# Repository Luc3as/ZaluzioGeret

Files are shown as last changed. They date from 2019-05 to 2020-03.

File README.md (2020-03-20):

# Zaluzio Geret
Automated smart blinds retrofit device with WiFi , MQTT and light measurement capability.



## Bill of material
* [Wemos D1 mini](http://s.click.aliexpress.com/e/b7xoMFF6) 
* [180 degree servo](http://s.click.aliexpress.com/e/cCIS5ETW)
* [LDR 5516 photoresistor](http://s.click.aliexpress.com/e/sKHeBEs)
* [NPN Transistor](http://s.click.aliexpress.com/e/bSLbOB7K)
* [Tactile push buttons](http://s.click.aliexpress.com/e/0rbMNuk)
* [10k Resistors](http://s.click.aliexpress.com/e/boawi0Ak)
* Some spring, hard to specify dimensions and power
* Some basic soldering equipment and skills

## Settings
You can redefine some default settings through Settings.h file. It is pretty self-explanatory I think.

## Usage
There is WiFi Manager on board so after burning the firmware, device is in AP mode, default password for connecting to AP is: configure.
Default account for configuring / controlling the device is admin with password: password

After connecting to WiFi, there is UI configuration interface, you can find device IP address through serial terminal or through in your router, or through scanning the network. Device hostname is ZaluzioGeret-MAC_END.

There are settings for specifiing MIN and MAX angle of rotation, and reverse direction of inner logic.

There are 2 buttons connected, UP and DOWN, each short press control the servo with 5° in respective direction. Short pressing of both buttons resets the servo in middle position. 
Long press of each button moves the servo to the MIN or MAX position defined. Long pressing of both buttons starts the LightFinder procedure. 
LightFinder procedure moves the servo to MIN position, and then continually measure light after each move. Then it move to the position in which highest light was measured. 

Long pressing of both buttons for 8 seconds resets the WiFi settings, putting the device into AP configuration mode. 

## Slave device controll
There is option in settings to setup Slave device ID which is automatically generated hostname which you can see in top of home screen. I assume using identical settings of PUB and SUB topic prefixes and also angles. 

When slave device ID is set, after pressing button, MQTT command will be sent to slave device and thus linking these together.

If you want to controll multiple devices remotely, not through buttons, you can easily done it in Home automation system, for example automation would have 2 actions, send command to 2 different topics. 

## MQTT Commands
```
  MQTTPUBTOPIC/hostname/LWT - Where status of device is sent 
  MQTTSUBTOPIC/hostname/Rotate  - Command for controlling angle of servo number expected
  MQTTSUBTOPIC/hostname/FindLight - Command for start LightFinder procedure. On expected
  MQTTPUBTOPIC/hostname/Light - Here is light measured sent
  MQTTPUBTOPIC/hostname/Angle - Here is current angle of servo sent
```

## API call / rest command
This call will start LightFinder procedure. 
You have to be authenticated or send basic auth with request.
``` 
ip.of.dev.ice/lightcontrol
```
This call will move servo to desired angle. 
You have to be authenticated or send basic auth with request.
``` 
ip.of.dev.ice/servocontrol?angle=XX
```

## Example Home Assisant configuration
```yaml
cover:
  - platform: mqtt
    name: "Žalúzie spálňa lavé"
    device_class: "blind"
    availability_topic: "stat/ZaluzioGeret-3252d1/LWT"
    qos: 0
    retain: false
    payload_available: "Online"
    payload_not_available: "Offline"
    optimistic: false
    value_template: '{{ value.x }}'
    tilt_command_topic: 'cmnd/ZaluzioGeret-3252d1/Rotate'
    tilt_status_topic: 'stat/ZaluzioGeret-3252d1/Angle'
    tilt_min: 0
    tilt_max: 180
    tilt_closed_value: 180
    tilt_opened_value: 90
    
  - platform: mqtt
    name: "Žalúzie spálňa pravé"
    device_class: "blind"
    availability_topic: "stat/ZaluzioGeret-5d26b9/LWT"
    qos: 0
    retain: false
    payload_available: "Online"
    payload_not_available: "Offline"
    optimistic: false
    value_template: '{{ value.x }}'
    tilt_command_topic: 'cmnd/ZaluzioGeret-5d26b9/Rotate'
    tilt_status_topic: 'stat/ZaluzioGeret-5d26b9/Angle'
    tilt_min: 0
    tilt_max: 180
    tilt_closed_value: 180
    tilt_opened_value: 90

  - platform: group
    name: "Žalúzie spálňa"
    entities:
      - cover.zaluzie_spalna_lave
      - cover.zaluzie_spalna_prave
```

## Wiring scheme
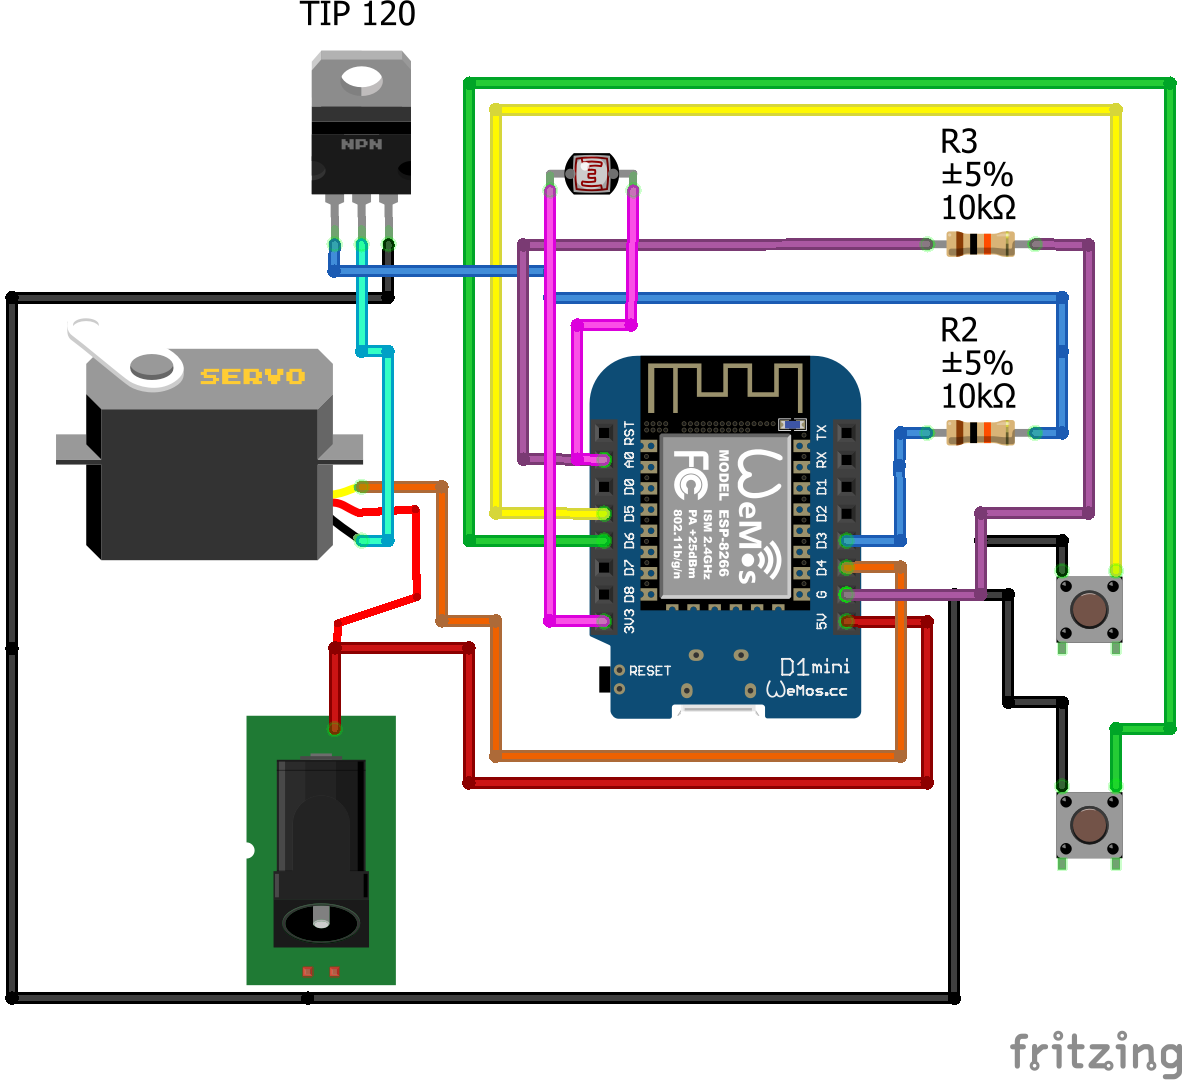
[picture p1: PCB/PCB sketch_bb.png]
Wiring scheme


## Physical installation
Device is mounted to window frame by self adhesive tape by 3M.

For cable routing I used sticky cable trunking with name MONTERA. 

All parts for 3D printing are on [thingiverse project page](https://www.thingiverse.com/thing:3679293)







### If You liked my work, You can buy me a coffee :)

<a class="" target="_blank" href="https://www.buymeacoffee.com/luc3as">Buy Me A Coffee</a>

### Or send some crypto

<a class="" target="_blank" href="https://lukasporubcan.sk/donate">Donate Bitcoin</a>

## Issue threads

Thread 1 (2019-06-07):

Some questions

davidhrbaty, 2019-06-07:
Hello Lukas,

Thank you for sharing this project. It looks very similar to what I want to build in the upcoming weeks.  I have a couple of questions.
When do you plan to share 3D models for the case?
How did you solve the problem with opening the window due to the power cable?
Did you consider mounting servo inside the sunblinds mechanism directly?

Thank you. Have a nice day.

Luc3as, 2019-06-08:
Hi,
good to read this, as always I was doing another projects and didn't get back to all TODOs I planned.
However today I slightly modified the base plate for this device and so right after that I uploaded it to thingiverse. You can find it here https://www.thingiverse.com/thing:3679293
I ran cables in thin cable organizer so there is no problem with opening the windows, I attached the cables in corner where the hinges are , and there is little reserve in bottom of window board.
Yes actually this is second or third design and I was playing with more options, at first I tried to pull ball chain with stepper motor, but it was too weak in my case, even after modifying the driver board. Second attemp was with continuos rotation servo, it is very similiar to this design, and it was doing great job, but I dropped this option because I would need to sense position of blinds somehow, I am sure there are ways to do this, I was thinking about some magnet attached to ball chain, and then sensing this magnet passing by reed switch somewhere on side of device. Or there could be some end stop switches attached but this means more cabling aand it would cause lower WAF (wife acceptance factor) :D
anyway this version is compatible with continuos rotation servos.
Sure I was thinking about putting all magic into the blinds cover, but  in my case I have very slim profiled sunblinds, so there is not enough room for this big servo. I saw some projects where bigger (older I guess) sunblinds was used and all electronics and motor was attached right there. You can find inspiration here if that is your case https://www.youtube.com/watch?v=s8kW8CoRJy0

davidhrbaty, 2019-06-10:
Hello,
Thank you for sharing your STL files. I will try it this weekend. Yes I know, that WAF is a top priority in all households :D. I was thinking about using the SG90 servo motor, which is very tiny and it can be integrated into sunblinds, but there can be a problem with torque. Now I'm looking, that you are from Slovakia too, so we can talk in our mother language ;).

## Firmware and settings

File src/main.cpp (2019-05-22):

/** The MIT License (MIT)

Copyright (c) 2019 Lukas Luc3as Porubcan

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
THE SOFTWARE IS PROVIDED "AS IS", WITHOUT WARRANTY OF ANY KIND, EXPRESS OR
IMPLIED, INCLUDING BUT NOT LIMITED TO THE WARRANTIES OF MERCHANTABILITY,
FITNESS FOR A PARTICULAR PURPOSE AND NONINFRINGEMENT. IN NO EVENT SHALL THE
AUTHORS OR COPYRIGHT HOLDERS BE LIABLE FOR ANY CLAIM, DAMAGES OR OTHER
LIABILITY, WHETHER IN AN ACTION OF CONTRACT, TORT OR OTHERWISE, ARISING FROM,
OUT OF OR IN CONNECTION WITH THE SOFTWARE OR THE USE OR OTHER DEALINGS IN THE
SOFTWARE.
*/

 /**********************************************
 * Edit Settings.h for personalization
 ***********************************************/

#include "Settings.h"

#define VERSION "1.3"

#define CONFIG "/conf.txt"

/* Useful Constants */
#define SECS_PER_MIN  (60UL)
#define SECS_PER_HOUR (3600UL)

/* Useful Macros for getting elapsed time */
#define numberOfSeconds(_time_) (_time_ % SECS_PER_MIN)  
#define numberOfMinutes(_time_) ((_time_ / SECS_PER_MIN) % SECS_PER_MIN) 
#define numberOfHours(_time_) (_time_ / SECS_PER_HOUR)

String hostname = "ZaluzioGeret-" + String(ESP.getChipId(), HEX);

WiFiUDP ntpUDP;
// Time 
NTPClient timeClient(ntpUDP, ntp_server , UtcOffset * 3600, 120000);

long lastEpoch = 0;
long firstEpoch = 0;
long displayOffEpoch = 0;
String lastMinute = "xx";
String lastSecond = "xx";
String lastReportStatus = "";

//declairing prototypes
void configModeCallback (WiFiManager *myWiFiManager);
int8_t getWifiQuality();

ESP8266WebServer server(WEBSERVER_PORT);
ESP8266HTTPUpdateServer serverUpdater;

String WEB_ACTIONS =  "<a class='w3-bar-item w3-button' href='/'><i class='fa fa-home'></i> Home</a>"
                      "<a class='w3-bar-item w3-button' href='/configure'><i class='fa fa-cog'></i> Configure</a>"
                      "<a class='w3-bar-item w3-button' href='/systemreset' onclick='return confirm(\"Do you want to reset to default settings?\")'><i class='fa fa-undo'></i> Reset Settings</a>"
                      "<a class='w3-bar-item w3-button' href='/forgetwifi' onclick='return confirm(\"Do you want to forget to WiFi connection?\")'><i class='fa fa-wifi'></i> Forget WiFi</a>"
                      "<a class='w3-bar-item w3-button' href='/update'><i class='fa fa-wrench'></i> Firmware Update</a>"
                      "<a class='w3-bar-item w3-button' href='/restart' onclick='return confirm(\"Do you want to restart device? Settings will persist.\")'><i class='fa fa-power-off'></i> Restart device</a>"
                      "<a class='w3-bar-item w3-button' href='https://github.com/Luc3as' target='_blank'><i class='fa fa-question-circle'></i> About</a>";
                          
String CHANGE_FORM =  "<form class='w3-container' action='/updateconfig' method='get'><h2>Device Config:</h2>"
                      "<p><label>MQTT Server address</label><input class='w3-input w3-border w3-margin-bottom' type='text' name='mqttAddress' value='%MQTTADDRESS%' maxlength='60'></p>"
                      "<p><label>MQTT Server Port</label><input class='w3-input w3-border w3-margin-bottom' type='text' name='mqttPort' value='%MQTTPORT%' maxlength='5'  onkeypress='return isNumberKey(event)'></p>"
                      "<p><label>MQTT Server User</label><input class='w3-input w3-border w3-margin-bottom' type='text' name='mqttUser' value='%MQTTUSER%' maxlength='30'></p>"
                      "<p><label>MQTT Server Password </label><input class='w3-input w3-border w3-margin-bottom' type='password' name='mqttPass' value='%MQTTPASS%'></p><hr>"
                      "<p><label>MQTT subscribe topic prefix ( prefix/hostname/topic )</label><input class='w3-input w3-border w3-margin-bottom' type='text' name='mqttSubTopic' value='%MQTTSUBTOPIC%' maxlength='30'></p>"
                      "<p><label>MQTT publish topic prefix ( prefix/hostname/topic )</label><input class='w3-input w3-border w3-margin-bottom' type='text' name='mqttPubTopic' value='%MQTTPUBTOPIC%' maxlength='30'></p>"
                      "<p><label>MQTT slave ID </label><input class='w3-input w3-border w3-margin-bottom' type='text' name='mqttSlaveId' value='%MQTTSLAVEID%' maxlength='30'></p><hr>"
                      "<p><input name='isreversedcontrol' class='w3-check w3-margin-top' type='checkbox' %IS_REVERSED_CONTROL%> Reverse direction of servo</p><hr>"
                      "<p><label>Minimal servo angle</label><input class='w3-input w3-border w3-margin-bottom' type='number' name='minAngle' value='%MINANGLE%' min'0' max'180'></p>"
                      "<p><label>Maximal servo angle</label><input class='w3-input w3-border w3-margin-bottom' type='number' name='maxAngle' value='%MAXANGLE%' min'0' max'180'></p>"
                      "<p><label>Maximal light intensity ( 0 - 1023 )</label><input class='w3-input w3-border w3-margin-bottom' type='number' name='maxLight' value='%MAXLIGHT%' min'0' max'1023'></p>";
                      
String THEME_FORM =   "<p>Theme Color <select class='w3-option w3-padding' name='theme'>%THEME_OPTIONS%</select></p>"
                      "<p>Clock Sync (minutes) <select class='w3-option w3-padding' name='refresh'>%OPTIONS%</select></p>"
                      "<p><label>UTC Time Offset</label><input class='w3-input w3-border w3-margin-bottom' type='text' name='utcoffset' value='%UTCOFFSET%' maxlength='12'></p><hr>"
                      "<p><input name='isBasicAuth' class='w3-check w3-margin-top' type='checkbox' %IS_BASICAUTH_CHECKED%> Use Security Credentials for Configuration Changes</p>"
                      "<p><label>User ID (for this interface)</label><input class='w3-input w3-border w3-margin-bottom' type='text' name='userid' value='%USERID%' maxlength='20'></p>"
                      "<p><label>Password </label><input class='w3-input w3-border w3-margin-bottom' type='password' name='stationpassword' value='%STATIONPASSWORD%'></p>"
                      "<button class='w3-button w3-block w3-grey w3-section w3-padding' type='submit'>Save</button></form>";

String COLOR_THEMES = "<option>red</option>"
                      "<option>pink</option>"
                      "<option>purple</option>"
                      "<option>deep-purple</option>"
                      "<option>indigo</option>"
                      "<option>blue</option>"
                      "<option>light-blue</option>"
                      "<option>cyan</option>"
                      "<option>teal</option>"
                      "<option>green</option>"
                      "<option>light-green</option>"
                      "<option>lime</option>"
                      "<option>khaki</option>"
                      "<option>yellow</option>"
                      "<option>amber</option>"
                      "<option>orange</option>"
                      "<option>deep-orange</option>"
                      "<option>blue-grey</option>"
                      "<option>brown</option>"
                      "<option>grey</option>"
                      "<option>dark-grey</option>"
                      "<option>black</option>"
                      "<option>w3schools</option>";

void writeSettings();
void handleWifiReset();
void handleServoControl();
void handleLightControl();
void handleUpdateConfig();
void handleConfigure();
void handleRestart();
void displayDeviceStatus();
void lightFinder();


void flashLED(int number, int delayTime) {
  for (int inx = 0; inx < number; inx++) {
      delay(delayTime);
      digitalWrite(externalLight, LOW);
      delay(delayTime);
      digitalWrite(externalLight, HIGH);
      delay(delayTime);
  }
}

void readSettings() {
  if (SPIFFS.exists(CONFIG) == false) {
    Serial.println("Settings File does not yet exists.");
    writeSettings();
    return;
  }
  File fr = SPIFFS.open(CONFIG, "r");
  String line;
  while(fr.available()) {
    line = fr.readStringUntil('\n');

    if (line.indexOf("UtcOffset=") >= 0) {
      UtcOffset = line.substring(line.lastIndexOf("UtcOffset=") + 10).toFloat();
      Serial.println("UtcOffset=" + String(UtcOffset));
    }
    if (line.indexOf("refreshRate=") >= 0) {
      minutesBetweenDataRefresh = line.substring(line.lastIndexOf("refreshRate=") + 12).toInt();
      Serial.println("minutesBetweenDataRefresh=" + String(minutesBetweenDataRefresh));
    }
    if (line.indexOf("themeColor=") >= 0) {
      themeColor = line.substring(line.lastIndexOf("themeColor=") + 11);
      themeColor.trim();
      Serial.println("themeColor=" + themeColor);
    }
    if (line.indexOf("IS_BASIC_AUTH=") >= 0) {
      IS_BASIC_AUTH = line.substring(line.lastIndexOf("IS_BASIC_AUTH=") + 14).toInt();
      Serial.println("IS_BASIC_AUTH=" + String(IS_BASIC_AUTH));
    }
    if (line.indexOf("www_username=") >= 0) {
      String temp = line.substring(line.lastIndexOf("www_username=") + 13);
      temp.trim();
      temp.toCharArray(www_username, sizeof(temp));
      Serial.println("www_username=" + String(www_username));
    }
    if (line.indexOf("www_password=") >= 0) {
      String temp = line.substring(line.lastIndexOf("www_password=") + 13);
      temp.trim();
      temp.toCharArray(www_password, sizeof(temp));
      Serial.println("www_password=" + String(www_password));
    }
    if (line.indexOf("DISPLAYCLOCK=") >= 0) {
      DISPLAYCLOCK = line.substring(line.lastIndexOf("DISPLAYCLOCK=") + 13).toInt();
      Serial.println("DISPLAYCLOCK=" + String(DISPLAYCLOCK));
    }
    if (line.indexOf("IS_REVERSED_CONTROL=") >= 0) {
      IS_REVERSED_CONTROL = line.substring(line.lastIndexOf("IS_REVERSED_CONTROL=") + 20).toInt();
      Serial.println("IS_REVERSED_CONTROL=" + String(IS_REVERSED_CONTROL));
    }    
    if (line.indexOf("MQTTADDRESS=") >= 0) {
      MQTTADDRESS = line.substring(line.lastIndexOf("MQTTADDRESS=") + 12);
      MQTTADDRESS.trim();
      Serial.println("MQTTADDRESS=" + String(MQTTADDRESS));
    }
    if (line.indexOf("MQTTPORT=") >= 0) {
      MQTTPORT = line.substring(line.lastIndexOf("MQTTPORT=") + 9).toInt();
      Serial.println("MQTTPORT=" + String(MQTTPORT));
    }    
    if (line.indexOf("MQTTUSER=") >= 0) {
      MQTTUSER = line.substring(line.lastIndexOf("MQTTUSER=") + 9);
      MQTTUSER.trim();
      Serial.println("MQTTUSER=" + String(MQTTUSER));
    }
    if (line.indexOf("MQTTPASS=") >= 0) {
      MQTTPASS = line.substring(line.lastIndexOf("MQTTPASS=") + 9);
      MQTTPASS.trim();
      Serial.println("MQTTPASS=" + String(MQTTPASS));
    }   
    if (line.indexOf("MQTTSUBTOPIC=") >= 0) {
      MQTTSUBTOPIC = line.substring(line.lastIndexOf("MQTTSUBTOPIC=") + 13);
      MQTTSUBTOPIC.trim();
      Serial.println("MQTTSUBTOPIC=" + String(MQTTSUBTOPIC));
    } 
    if (line.indexOf("MQTTPUBTOPIC=") >= 0) {
      MQTTPUBTOPIC = line.substring(line.lastIndexOf("MQTTPUBTOPIC=") + 13);
      MQTTPUBTOPIC.trim();
      Serial.println("MQTTPUBTOPIC=" + String(MQTTPUBTOPIC));
    }
    if (line.indexOf("MQTTSLAVEID=") >= 0) {
      MQTTSLAVEID = line.substring(line.lastIndexOf("MQTTSLAVEID=") + 12);
      MQTTSLAVEID.trim();
      Serial.println("MQTTSLAVEID=" + String(MQTTSLAVEID));
    }
    if (line.indexOf("MINANGLE=") >= 0) {
      MINANGLE = line.substring(line.lastIndexOf("MINANGLE=") + 9).toInt();
      Serial.println("MINANGLE=" + String(MINANGLE));
    }
    if (line.indexOf("MAXANGLE=") >= 0) {
      MAXANGLE = line.substring(line.lastIndexOf("MAXANGLE=") + 9).toInt();
      Serial.println("MAXANGLE=" + String(MAXANGLE));
    }      
    if (line.indexOf("MAXLIGHT=") >= 0) {
      MAXLIGHT = line.substring(line.lastIndexOf("MAXLIGHT=") + 9).toInt();
      Serial.println("MAXLIGHT=" + String(MAXLIGHT));
    }         
  }
  fr.close();
  timeClient.setTimeOffset(UtcOffset * 3600);
  LWTTopic = MQTTPUBTOPIC + "/" + hostname + "/LWT";
  SUBTopic = MQTTSUBTOPIC + "/" + hostname + "/Rotate";
  SUBTopicLight = MQTTSUBTOPIC + "/" + hostname + "/FindLight";
  PUBTopicLight = MQTTPUBTOPIC + "/" + hostname + "/Light";
  PUBTopicAngle = MQTTPUBTOPIC + "/" + hostname + "/Angle";
  SlaveTopic = MQTTSUBTOPIC + "/" + MQTTSLAVEID + "/Rotate";

}

void writeSettings() {
  // Save decoded message to SPIFFS file for playback on power up.
  File f = SPIFFS.open(CONFIG, "w");
  if (!f) {
    Serial.println("File open failed!");
  } else {
    Serial.println("Saving settings now...");
    f.println("UtcOffset=" + String(UtcOffset));
    f.println("refreshRate=" + String(minutesBetweenDataRefresh));
    f.println("themeColor=" + themeColor);
    f.println("IS_BASIC_AUTH=" + String(IS_BASIC_AUTH));
    f.println("www_username=" + String(www_username));
    f.println("www_password=" + String(www_password));
    f.println("DISPLAYCLOCK=" + String(DISPLAYCLOCK));
    f.println("IS_REVERSED_CONTROL=" + String(IS_REVERSED_CONTROL));
    f.println("MQTTADDRESS=" + String(MQTTADDRESS));
    f.println("MQTTPORT=" + String(MQTTPORT));
    f.println("MQTTUSER=" + String(MQTTUSER));
    f.println("MQTTPASS=" + String(MQTTPASS));
    f.println("MQTTSUBTOPIC=" + String(MQTTSUBTOPIC));
    f.println("MQTTPUBTOPIC=" + String(MQTTPUBTOPIC));
    f.println("MQTTSLAVEID=" + String(MQTTSLAVEID));
    f.println("MINANGLE=" + String(MINANGLE));
    f.println("MAXANGLE=" + String(MAXANGLE));
    f.println("MAXLIGHT=" + String(MAXLIGHT));
  }
  f.close();
  readSettings();
  timeClient.setTimeOffset(UtcOffset * 3600);
}

void findMDNS() {
  if ( ENABLE_OTA == false) {
    return; // nothing to do here
  }
  // We now query our network for 'web servers' service
  // over tcp, and get the number of available devices
  int n = MDNS.queryService("mqtt", "tcp");
  if (n == 0) {
    Serial.println("no services found - make sure server is turned on");
    return;
  }
  Serial.println("*** Looking for MQTT over mDNS");
  for (int i = 0; i < n; ++i) {
    // Going through every available service,
    // we're searching for the one whose hostname
    // matches what we want, and then get its IP
    Serial.println("Found: " + MDNS.hostname(i));
    if (MDNS.hostname(i) == "mqtt.local") {
      IPAddress serverIp = MDNS.IP(i);
      String MQTTServer = serverIp.toString();
      int16_t MQTTPort = MDNS.port(i); // save the port
      Serial.println("*** Found OctoPrint Server " + MDNS.hostname(i) + " http://" + MQTTServer + ":" + MQTTPort);
      writeSettings(); // update the settings
    }
  }
}

boolean authentication() {
  if (IS_BASIC_AUTH && (strlen(www_username) >= 1 && strlen(www_password) >= 1)) {
    return server.authenticate(www_username, www_password);
  } 
  return true; // Authentication not required
}

String getHeader(boolean refresh=false) {
  String menu = WEB_ACTIONS;

  String html = "<!DOCTYPE HTML>";
  html += "<html><head><title>ZaluzioGeret</title><link rel='icon' href='data:;base64,='>";
  html += "<meta charset='UTF-8'>";
  html += "<meta name='viewport' content='width=device-width, initial-scale=1'>";
  if (refresh) {
    html += "<meta http-equiv=\"refresh\" content=\"15\">";
  }
  html += "<link rel='stylesheet' href='https://www.w3schools.com/w3css/4/w3.css'>";
  html += "<link rel='stylesheet' href='https://www.w3schools.com/lib/w3-theme-" + themeColor + ".css'>";
  html += "<link rel='stylesheet' href='https://use.fontawesome.com/releases/v5.8.1/css/all.css' integrity='sha384-50oBUHEmvpQ+1lW4y57PTFmhCaXp0ML5d60M1M7uH2+nqUivzIebhndOJK28anvf' crossorigin='anonymous'>";
  html += "</head><body>";
  html += "<nav class='w3-sidebar w3-bar-block w3-card' style='margin-top:88px' id='mySidebar'>";
  html += "<div class='w3-container w3-theme-d2'>";
  html += "<span onclick='closeSidebar()' class='w3-button w3-display-topright w3-large'><i class='fa fa-times'></i></span>";
  html += "<div class='w3-cell w3-left w3-xxxlarge' style='width:60px'><i class='fa fa-cloud-sun'></i></div>";
  html += "<div class='w3-padding'>Menu</div></div>";
  html += menu;
  html += "</nav>";
  html += "<header class='w3-top w3-bar w3-theme'><button class='w3-bar-item w3-button w3-xxxlarge w3-hover-theme' onclick='openSidebar()'><i class='fa fa-bars'></i></button><h2 class='w3-bar-item'>Zaluzio Geret</h2></header>";
  html += "<script>";
  html += "function openSidebar(){document.getElementById('mySidebar').style.display='block'}function closeSidebar(){document.getElementById('mySidebar').style.display='none'}closeSidebar();";
  html += "</script>";
  html += "<br><div class='w3-container w3-large' style='margin-top:88px'>";
  return html;
}
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
void loop() {

  now = millis();
   
  //Get Time Update
  if((getMinutesFromLastRefresh() >= minutesBetweenDataRefresh) || lastEpoch == 0) {
    getUpdateTime();
  }

  if (WEBSERVER_ENABLED) {
    server.handleClient();
  }
  if (ENABLE_OTA) {
    ArduinoOTA.handle();
  }

  // Check MQTT connection
  if (!client.connected()) {
      reconnectMQTT();
  }

  // MQTT client loop check new messages
  client.loop();

  // Measure the light intensity
  measureLight();

  // Handle buttons
  handleButtons();
}

void handleServoControl() {
  if (!authentication()) {
    return server.requestAuthentication();
  }
  String t_angle = server.arg("angle"); //Refer  
  Serial.print("AJAX Servo control request: ");
  Serial.println(t_angle);
  controlServo(t_angle.toInt());
  server.send(200, "text/plane", String(actualServoAngle)); //Send web page
}

void handleLightControl() {
  if (!authentication()) {
    return server.requestAuthentication();
  }
  Serial.println("AJAX LightFinder control request: START");
  server.send(200, "text/plane", "Finding light..."); //Send web page
  lightFinder();
}

void handleUpdateConfig() {
  if (!authentication()) {
    return server.requestAuthentication();
  }
  String temp;
  MQTTADDRESS = server.arg("mqttAddress");
  MQTTPORT = server.arg("mqttPort").toInt();
  MQTTUSER = server.arg("mqttUser");
  MQTTPASS = server.arg("mqttPass");
  MQTTSUBTOPIC = server.arg("mqttSubTopic");
  MQTTPUBTOPIC = server.arg("mqttPubTopic");
  MQTTSLAVEID = server.arg("mqttSlaveId");
  DISPLAYCLOCK = server.hasArg("isClockEnabled");
  IS_REVERSED_CONTROL = server.hasArg("isreversedcontrol");
  minutesBetweenDataRefresh = server.arg("refresh").toInt();
  themeColor = server.arg("theme");
  UtcOffset = server.arg("utcoffset").toFloat();
  temp = server.arg("userid");
  temp.toCharArray(www_username, sizeof(temp));
  temp = server.arg("stationpassword");
  temp.toCharArray(www_password, sizeof(temp));
  MINANGLE = server.arg("minAngle").toInt();
  MAXANGLE = server.arg("maxAngle").toInt();
  MAXLIGHT = server.arg("maxLight").toInt();

  writeSettings();
  findMDNS();
  lastEpoch = 0;
  redirectHome();
  reconnectMQTT();
}

String getUptime() {
  unsigned long nowMillis = millis();
  unsigned long seconds = nowMillis / 1000;
  int days = seconds / 86400;
  seconds %= 86400;
  byte hours = seconds / 3600;
  seconds %= 3600;
  byte minutes = seconds / 60;
  seconds %= 60;
  String timeFormated ;
  timeFormated = String(days) + " days, " + String(hours) + " hours, " + String(minutes) + " minutes, " + String(seconds) + " seconds";
  return(timeFormated);
}

void displayDeviceStatus() {
  digitalWrite(externalLight, LOW);
  String html = "";

  server.sendHeader("Cache-Control", "no-cache, no-store");
  server.sendHeader("Pragma", "no-cache");
  server.sendHeader("Expires", "-1");
  server.setContentLength(CONTENT_LENGTH_UNKNOWN);
  server.send(200, "text/html", "");
  server.sendContent(String(getHeader(true)));

  String displayTime = timeClient.getFormattedTime() ;
  
  html += "<div class='w3-cell-row' style='width:100%'><h2>Time: " + displayTime + "</h2></div><div class='w3-cell-row'>";
  html += "<div class='w3-cell w3-container' style='width:100%'><p>";
  html += "Host Name: " + hostname + "<br>";
  html += "Uptime: " + getUptime() + "<br>";  
  html += "<hr> <h2>Blinds position: </h2> <br>";
  html += "<input type='range' style='min-width: 50%;' min='" + String(MINANGLE) + "' max='" + String(MAXANGLE) + "' value='" + String(actualServoAngle) + "' class='slider' \ 
  id='angleSlider' onChange='moveServo()'>  <br>";
  html += "<script>function moveServo(){ var xhttp = new XMLHttpRequest();xhttp.onreadystatechange = function(){ \
    if (this.readyState == 4 && this.status == 200){ document.getElementById('angleSlider').value = this.responseText; } }; \
    xhttp.open('get', 'servocontrol?angle='+ document.getElementById('angleSlider').value); xhttp.send(); } </script>";
  html += "<button class='w3-button w3-yellow w3-section w3-padding' style='min-width: 50%;' type='button' \
  id='LightFinder' onClick='findLight()'> LightFinder </button> <br>";
  html += "<script>function findLight(){ var xhttp = new XMLHttpRequest();xhttp.onreadystatechange = function(){ \
    if (this.readyState == 4 && this.status == 200){ document.getElementById('LightFinder').innerHTML = this.responseText; } }; \
    xhttp.open('get', 'lightcontrol?'); xhttp.send(); } </script>";

  html += "</p></div></div>";

  server.sendContent(html); // spit out what we got
  html = "";

  server.sendContent(String(getFooter()));
  server.sendContent("");
  server.client().stop();
  digitalWrite(externalLight, HIGH);
}

void configModeCallback (WiFiManager *myWiFiManager) {
  Serial.println("Entered config mode");
  Serial.println(WiFi.softAPIP());
  
  Serial.println("Wifi Manager");
  Serial.println("Please connect to AP");
  Serial.println(myWiFiManager->getConfigPortalSSID());
  Serial.println("To setup Wifi Configuration");
  flashLED(20, 50);
}

// converts the dBm to a range between 0 and 100%
int8_t getWifiQuality() {
  int32_t dbm = WiFi.RSSI();
  if(dbm <= -100) {
      return 0;
  } else if(dbm >= -50) {
      return 100;
  } else {
      return 2 * (dbm + 100);
  }
}

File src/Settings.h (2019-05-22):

/** The MIT License (MIT)

Copyright (c) 2019 Lukas Luc3as Porubcan

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
THE SOFTWARE IS PROVIDED "AS IS", WITHOUT WARRANTY OF ANY KIND, EXPRESS OR
IMPLIED, INCLUDING BUT NOT LIMITED TO THE WARRANTIES OF MERCHANTABILITY,
FITNESS FOR A PARTICULAR PURPOSE AND NONINFRINGEMENT. IN NO EVENT SHALL THE
AUTHORS OR COPYRIGHT HOLDERS BE LIABLE FOR ANY CLAIM, DAMAGES OR OTHER
LIABILITY, WHETHER IN AN ACTION OF CONTRACT, TORT OR OTHERWISE, ARISING FROM,
OUT OF OR IN CONNECTION WITH THE SOFTWARE OR THE USE OR OTHER DEALINGS IN THE
SOFTWARE.
*/

#include <ESP8266WiFi.h>
#include <ESP8266WebServer.h>
#include <WiFiManager.h>
#include <ESP8266mDNS.h>
#include <ArduinoOTA.h>
#include <ESP8266HTTPUpdateServer.h>
#include "FS.h"
#include <ArduinoJson.h>          //https://github.com/bblanchon/ArduinoJson
#include <PubSubClient.h>
#include <Servo.h>
#include <Wire.h>
#include <NTPClient.h>
#include <WiFiUdp.h>

// Constants and initializations
String themeColor = "light-green"; // this can be changed later in the web interface.
unsigned long lastSend;
int counter = 0;
WiFiClient espClient;
PubSubClient client(espClient);


//******************************
// Start Settings
//******************************

// Peripherals 
int servoPIN = D4;
int servoEnablePIN = D3;
int LDRPIN = A0;
Servo blinds;
int MINANGLE = 0;
int MAXANGLE = 180;
int MAXLIGHT = 1023;
int lightPercent = -1;
int actualServoAngle = 90;
int buttonUp = D5;
int buttonDown = D6;
long buttonTimer = 0;   // For counting time the button is presed
long longPressTime = 750;  // How long is considered as long-press of button (miliseconds)
long megaLongPressTime = 8 * 1000;  // How long is considered as long-press of button (miliseconds)
boolean buttonActive = false;
boolean longPressActive = false;
boolean megaLongPressActive = false;
boolean buttonUpActive = false;
boolean buttonDownActive = false;

// Webserver
const int WEBSERVER_PORT = 80; // The port you can access this device on over HTTP
const boolean WEBSERVER_ENABLED = true;  // Device will provide a web interface via http://[ip]:[port]/
boolean IS_BASIC_AUTH = true;  // true = require athentication to change configuration settings / false = no auth
char* www_username = "admin";  // User account for the Web Interface
char* www_password = "password";  // Password for the Web Interface
String MQTTADDRESS; 
String MQTTUSER ;
String MQTTPASS ;
int MQTTPORT;
String MQTTSUBTOPIC ;
String MQTTPUBTOPIC ;
String MQTTSLAVEID ;
const char* on_cmd = "ON";
const char* off_cmd = "OFF";
const char* will_msg = "Offline";
const char* online_msg = "Online";
int sendInterval = 5;
String LWTTopic ;
String SUBTopic ;
String SUBTopicLight ;
String PUBTopicLight ;
String PUBTopicAngle ;
String SlaveTopic;

// Date and Time
float UtcOffset = +2; // Hour offset from GMT for your timezone
boolean IS_REVERSED_CONTROL = false;  
const char* ntp_server = "eu.pool.ntp.org";
int minutesBetweenDataRefresh = 15;
boolean DISPLAYCLOCK = true;   // true = Show Clock when not printing / false = turn off display when not printing
long now ;

// LED Settings
const int externalLight = D1; // Set to unused pin, like D1, to disable use of built-in LED (LED_BUILTIN)

// OTA Updates
boolean ENABLE_OTA = true;     // this will allow you to load firmware to the device over WiFi (see OTA for ESP8266)
String OTA_Password = "";      // Set an OTA password here -- leave blank if you don't want to be prompted for password

//******************************
// End Settings
//******************************

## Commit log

2019-04-11 stage .
2019-04-14 added handling of buttons
2019-04-23 fixnute handlovanie tlacidiel, dorobeny ajax web control uhla
    [main.cpp]
2019-04-24 fixed reverse direction angle acknowledge
    [main.cpp]
2019-05-15 added PCB sketch
    [PCB sketch.fzz]
2019-05-21 added mega long press for resetting wifi settings
    [Settings.h, main.cpp]
2019-05-21 fixed very long press for forgetting wifi details fixed some serial output of lightfinder function changed inner working of button press
    [Settings.h, main.cpp]
2019-05-22 added light finder button into UI
2019-05-22 added slave device control updated readme
